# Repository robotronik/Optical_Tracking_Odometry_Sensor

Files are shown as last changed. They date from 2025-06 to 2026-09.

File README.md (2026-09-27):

Robotronik Optical Tracking Odometry Sensor
========================================

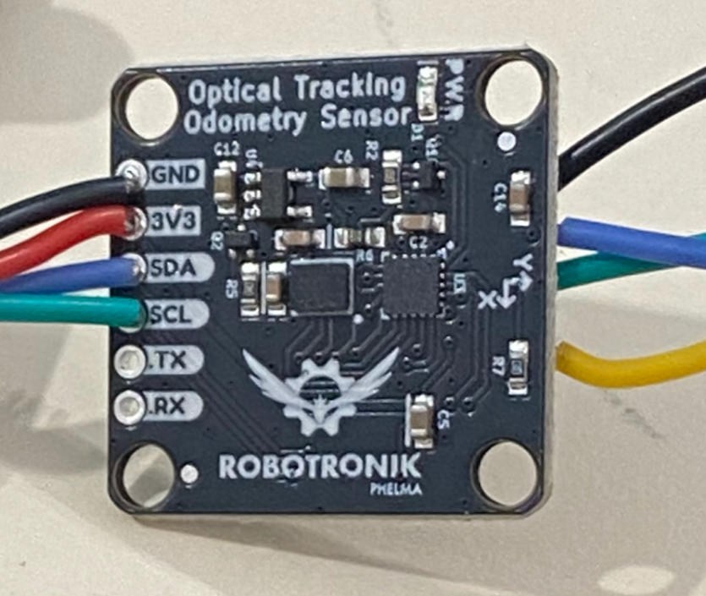
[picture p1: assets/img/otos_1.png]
Robotronik Optical Tracking Odometry Sensor [SEN-24904]


[*Robotronik Optical Tracking Odometry Sensor [SEN-24904]*](https://www.sparkfun.com/products/24904)

The Robotronik Optical Tracking Odometry Sensor empowers you to elevate your robot's navigation capabilities with exceptional precision and streamlined integration. This compact, all-in-one sensor leverages the power of the PAA5163E1 chip from PixArt Imaging Inc., delivering accurate dual-axis motion data across various hard floor surfaces. But that's not all! This sensor boasts a powerful built-in 6-axis Inertial Measurement Unit (IMU) and an onboard microcontroller that performs real-time sensor fusion and tracking algorithms.

Repository Contents
-------------------

* **/Hardware** - Kicad 9 Design
* **/Production** - Production panel files

Documentation
--------------
* **[Arduino Library](https://github.com/sparkfun/SparkFun_Qwiic_OTOS_Arduino_Library)** - Arduino library for the SparkFun Optical Tracking Odometry Sensor.
* **[Hookup Guide](https://docs.sparkfun.com/SparkFun_Optical_Tracking_Odometry_Sensor/)** - Hookup guide for the SparkFun Optical Tracking Odometry Sensor.

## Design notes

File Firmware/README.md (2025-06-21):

# SparkFun OTOS (Optical Tracking Odometry Sensor) Firmware

This folder contains the firmware used on the [SparkFun Optical Tracking Odometry Sensor](https://www.sparkfun.com/products/24904). Instructions are provided below for anyone wanting to change the firmware on their OTOS.

## Firmware Update

The recommended update procedure is to use the [STM32CubeProgrammer](https://www.st.com/en/development-tools/stm32cubeprog.html) to flash the provided .hex firmware file using the UART interface. The SWD test points on the OTOS can also be used with a debugger, but instructions are not provided here.

### Required Materials

* A [SparkFun Optical Tracking Odometry Sensor](https://www.sparkfun.com/products/24904) to be updated
* A USB to serial adapter, such as the [SparkFun Serial Basic Breakout](https://www.sparkfun.com/products/15096)
* [Jumper wires](https://www.sparkfun.com/products/12795) to connect the serial adapter to the OTOS
* Download the [STM32CubeProgrammer](https://www.st.com/en/development-tools/stm32cubeprog.html) and install it onto your computer
* Download the latest .hex file [from the releases tab](https://github.com/sparkfun/SparkFun_Optical_Tracking_Odometry_Sensor/releases) or [from the main branch](https://github.com/sparkfun/SparkFun_Optical_Tracking_Odometry_Sensor/tree/main/Firmware/Release)

### Procedure

1. The STM32 on the OTOS needs to be running its bootloader to flash the new firmware.
    * To do this, the BOOT0 pin must be held high when the STM32 boots up (during power up or a reset). This is broken out to the centermost test point on the bottom of the OTOS. It is suggested to touch a jumper wire connected to 3.3V to this test point while powering up the board - the STM32 will remain in the bootloader until it resets, loses power, or new code is flashed onto it.
2. Connect the serial converter TX and RX pins to IO10 and IO9 respectively.
3. Open the STM32CubeProgrammer. In the top right, select the UART interface, leave the UART configuration at the default settings, and click the Connect button.
    * If it fails to connect, ensure the right COM port is selected and is not used by anything else on your computer, ensure the OTOS is fully powered, ensure the bootloader is running (see Step 1), and ensure the TX and RX pins are correct.
4. Once connected, select the "Erasing & programming" tab on the left. In the "Download" section, select the .hex file to be flashed in the File path, then click "Start Programming"
5. Once complete, the OTOS should start running the new firmware immediately, and will disconnect from the STM32CubeProgrammer.

## Building the Firmware

The firmware was developed using the [STM32CubeIDE](https://www.st.com/en/development-tools/stm32cubeide.html), which you will need to install in order to build the firmware. It generates code for the low-level hardware functionality, so be aware that code within the `Core` directory may be modified by the code generator if not placed in the correct locations.

To import the project, open the STM32CubeIDE -> File -> Import... -> General -> Existing Projects into Workspace -> Next -> set root directory to this folder called Firmware -> Ensure SparkFun_OTOS_Firmware is selected -> Finish. You should now see the SparkFun_OTOS_Firmware project in the Project Explorer on the left. Once open, you should also change the build configuration from Debug to Release: Project -> Build Configurations -> Set Active -> 2 Release.

To build the project, within the STM32CubeIDE, -> Project -> Build Project. The output .hex file will be placed in the `Release` directory (assuming you've changed the build configuration from Debug to Release).

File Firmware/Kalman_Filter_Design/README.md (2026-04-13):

# SparkFun OTOS Kalman Filter Design

This folder contains the simulation that was used to design the Kalman filter for the [SparkFun Optical Tracking Odometry Sensor](https://www.sparkfun.com/products/24904). This script can be run in either [MATLAB](https://www.mathworks.com/products/matlab.html) (not tested) or [GNU Octave](https://octave.org/) (free). This is mainly provided for transparency on how the Kalman filter was designed and tuned, although you're welcome to play around with it and try to improve it!

The Kalman filter is what performs the sensor fusion between the acceleration measurements from the IMU (LSM6DSO), and the velocity measurements from the optical tracking sensor (PAA5163). The LSM6DSO acceleration measurements were measured to have a standard deviation of about 0.03 m/s^2, and the PAA5163 velocity measurements were measured to have a standard deviation of about 3 in/s (0.076 m/s).

The process noise covariance matrix Q was manually tuned to give a good balance of fast response times and low noise. The simulation also includes a handful of tests to verify robustness, such as loss of optical tracking data and acceleration offsets.

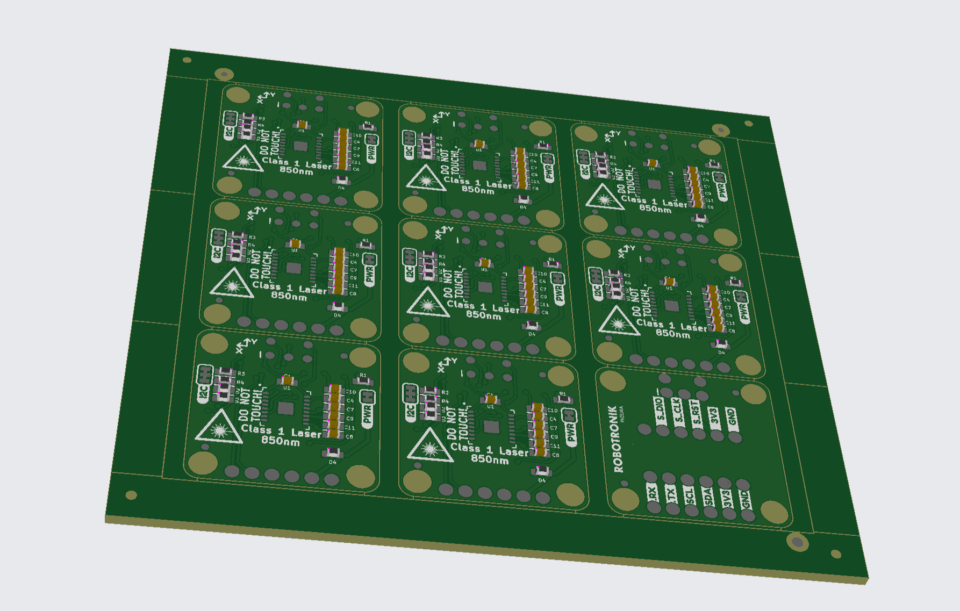
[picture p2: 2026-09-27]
assets/img/panel_jlc_1.png

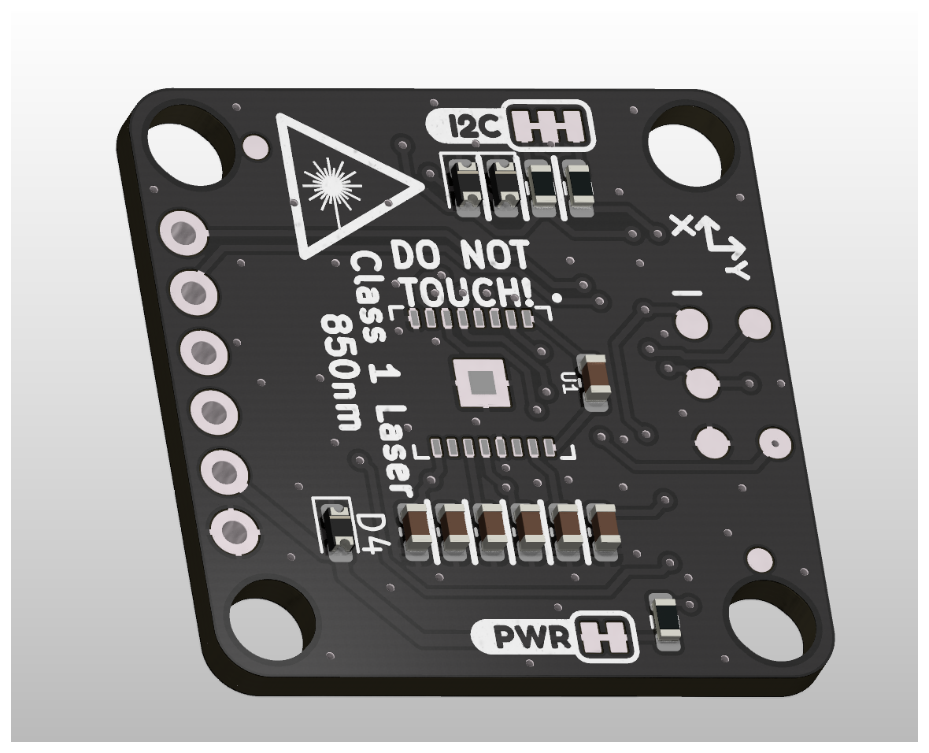
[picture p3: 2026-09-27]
assets/img/otos_cad_bot.png

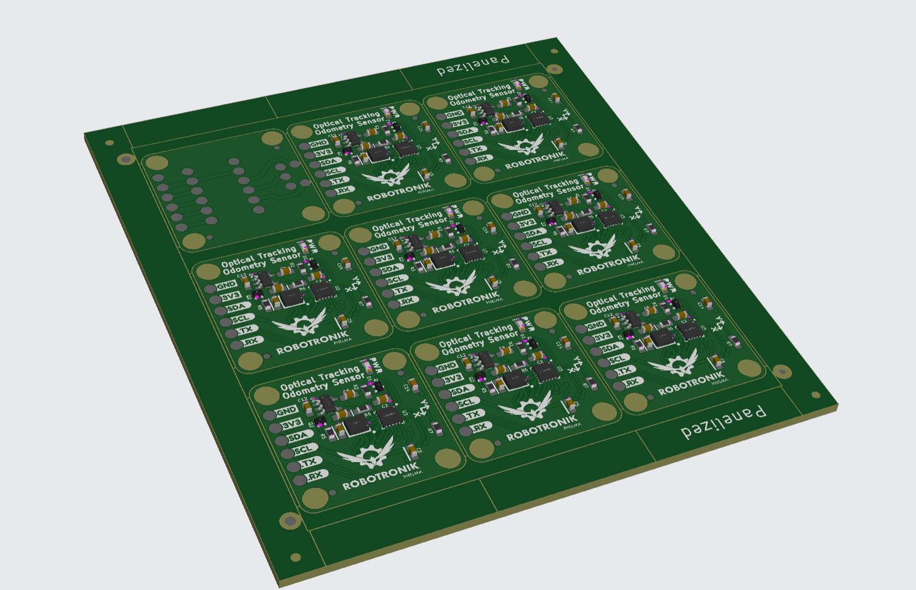
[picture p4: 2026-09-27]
assets/img/panel_jlc_2.png

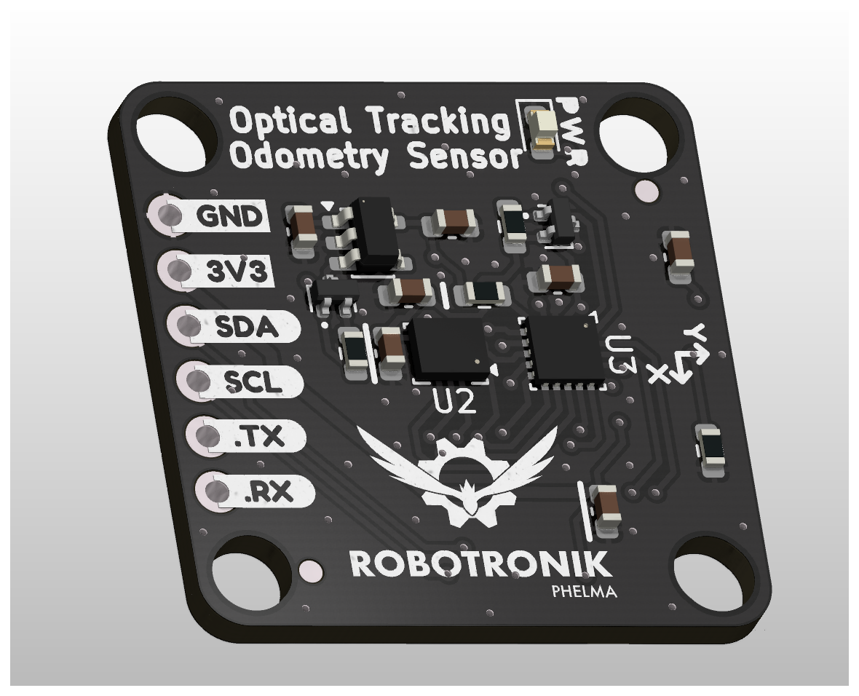
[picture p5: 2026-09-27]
assets/img/otos_cad_top.png

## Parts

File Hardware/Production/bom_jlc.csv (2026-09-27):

Designator | Footprint | Quantity | Value | LCSC Part #
C1_8, C1_7, C1_6, C1_5, C1_4, C1_3, C1_2, C1 | 603 | 8 | 470pF | C1620
C10_8, C10_7, C10_6, C10_5, C10_4, C10_3, C10_2, C10, C11_8, C11_7, C11_6, C11_5, C11_4, C11_3, C11_2, C11 | 603 | 16 | 4.7uF | C19666
C12_8, C12_7, C12_6, C12_5, C12_4, C12_3, C12_2, C12, C5_8, C5_7, C5_6, C5_5, C5_4, C5_3, C5_2, C5, C6_8, C6_7, C6_6, C6_5, C6_4, C6_3, C6_2, C6 | 603 | 24 | 22uF | C59461
C13_8, C13_7, C13_6, C13_5, C13_4, C13_3, C13_2, C13, C14_8, C14_7, C14_6, C14_5, C14_4, C14_3, C14_2, C14, C2_8, C2_7, C2_6, C2_5, C2_4, C2_3, C2_2, C2, C3_8, C3_7, C3_6, C3_5, C3_4, C3_3, C3_2, C3, C4_8, C4_7, C4_6, C4_5, C4_4, C4_3, C4_2, C4, C7_8, C7_7, C7_6, C7_5, C7_4, C7_3, C7_2, C7, C8_8, C8_7, C8_6, C8_5, C8_4, C8_3, C8_2, C8, C9_8, C9_7, C9_6, C9_5, C9_4, C9_3, C9_2, C9 | 603 | 64 | 0.1uF | C14663
D1_8, D1_7, D1_6, D1_5, D1_4, D1_3, D1_2, D1 | LED-0603 | 8 | Blue | C2286
D2_8, D2_7, D2_6, D2_5, D2_4, D2_3, D2_2, D2, D3_8, D3_7, D3_6, D3_5, D3_4, D3_3, D3_2, D3, D4_8, D4_7, D4_6, D4_5, D4_4, D4_3, D4_2, D4 | 603 | 24 | 24V | C2929252
Q1_8, Q1_7, Q1_6, Q1_5, Q1_4, Q1_3, Q1_2, Q1, Q2_8, Q2_7, Q2_6, Q2_5, Q2_4, Q2_3, Q2_2, Q2 | SOT-416FL | 16 | 100mA/20V/3.8Ω | C703629
R1_8, R1_7, R1_6, R1_5, R1_4, R1_3, R1_2, R1 | 603 | 8 | 4.7k | C23162
R2_8, R2_7, R2_6, R2_5, R2_4, R2_3, R2_2, R2, R5_8, R5_7, R5_6, R5_5, R5_4, R5_3, R5_2, R5, R7_8, R7_7, R7_6, R7_5, R7_4, R7_3, R7_2, R7 | 603 | 24 | 100k | C25803
R3_8, R3_7, R3_6, R3_5, R3_4, R3_3, R3_2, R3, R4_8, R4_7, R4_6, R4_5, R4_4, R4_3, R4_2, R4 | 603 | 16 | 2.2k | C4190
R6_8, R6_7, R6_6, R6_5, R6_4, R6_3, R6_2, R6 | 603 | 8 | 1k | C21190
U2_8, U2_7, U2_6, U2_5, U2_4, U2_3, U2_2, U2 | LGA14L | 8 | LSM6DS0 | C2829074
U3_8, U3_7, U3_6, U3_5, U3_4, U3_3, U3_2, U3 | STM32C011F6U6 | 8 | STM32C011F6U6 | C5456206
U4_8, U4_7, U4_6, U4_5, U4_4, U4_3, U4_2, U4 | SOT23-5 | 8 | RT9080-18GJ5 | C426476

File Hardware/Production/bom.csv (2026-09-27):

Designator | Footprint | Quantity | Value | LCSC Part #
_34, _33, _32, _31, _30, _29, _28, _27, _26, _25, _24, _23, _22, _21, _20, _19, _18, _17, _16, _15, _14, _13, _12, _11, _10, _9, _8 |  | 27
C1_8, C1_7, C1_6, C1_5, C1_4, C1_3, C1_2, C1 | 0603 | 8 | 470pF
C10_8, C10_7, C10_6, C10_5, C10_4, C10_3, C10_2, C10, C11_8, C11_7, C11_6, C11_5, C11_4, C11_3, C11_2, C11 | 0603 | 16 | 4.7uF
C12_8, C12_7, C12_6, C12_5, C12_4, C12_3, C12_2, C12, C5_8, C5_7, C5_6, C5_5, C5_4, C5_3, C5_2, C5, C6_8, C6_7, C6_6, C6_5, C6_4, C6_3, C6_2, C6 | 0603 | 24 | 22uF
C13_8, C13_7, C13_6, C13_5, C13_4, C13_3, C13_2, C13, C14_8, C14_7, C14_6, C14_5, C14_4, C14_3, C14_2, C14, C2_8, C2_7, C2_6, C2_5, C2_4, C2_3, C2_2, C2, C3_8, C3_7, C3_6, C3_5, C3_4, C3_3, C3_2, C3, C4_8, C4_7, C4_6, C4_5, C4_4, C4_3, C4_2, C4, C7_8, C7_7, C7_6, C7_5, C7_4, C7_3, C7_2, C7, C8_8, C8_7, C8_6, C8_5, C8_4, C8_3, C8_2, C8, C9_8, C9_7, C9_6, C9_5, C9_4, C9_3, C9_2, C9 | 0603 | 64 | 0.1uF
D1_8, D1_7, D1_6, D1_5, D1_4, D1_3, D1_2, D1 | LED-0603 | 8 | Blue
D2_8, D2_7, D2_6, D2_5, D2_4, D2_3, D2_2, D2, D3_8, D3_7, D3_6, D3_5, D3_4, D3_3, D3_2, D3, D4_8, D4_7, D4_6, D4_5, D4_4, D4_3, D4_2, D4 | 0603 | 24 | 24V
FD1_9, FD1_8, FD1_7, FD1_6, FD1_5, FD1_4, FD1_3, FD1_2, FD1, FD2_9, FD2_8, FD2_7, FD2_6, FD2_5, FD2_4, FD2_3, FD2_2, FD2, FD3_9, FD3_8, FD3_7, FD3_6, FD3_5, FD3_4, FD3_3, FD3_2, FD3, FD4_9, FD4_8, FD4_7, FD4_6, FD4_5, FD4_4, FD4_3, FD4_2, FD4 | FIDUCIAL-1X2 | 36 | FIDUCIAL1X2
FRAME1 | CREATIVE_COMMONS | 1 | FRAME-LETTER
H1_18, H1_17, H1_16, H1_15, H1_14, H1_13, H1_12, H1_11, H1_10, H1_9, H1_8, H1_7, H1_6, H1_5, H1_4, H1_3, H1_2, H1, H2_9, H2_8, H2_7, H2_6, H2_5, H2_4, H2_3, H2_2, H2, H3_9, H3_8, H3_7, H3_6, H3_5, H3_4, H3_3, H3_2, H3, H4_9, H4_8, H4_7, H4_6, H4_5, H4_4, H4_3, H4_2, H4 | STAND-OFF | 45 | STAND-OFF
I2C0_8, I2C0_7, I2C0_6, I2C0_5, I2C0_4, I2C0_3, I2C0_2, I2C0 | SMT-JUMPER_3_2-NC_TRACE_SILK | 8 | JUMPER-SMT_3_2-NC_TRACE_SILK
J3_11, J3_10, J3_9, J3_8, J3_7, J3_6, J3_5, J3_4, J3_3, J3_2, J3 | 1X06_NO_SILK | 11 | CONN_06NO_SILK_NO_POP
PWR0_8, PWR0_7, PWR0_6, PWR0_5, PWR0_4, PWR0_3, PWR0_2, PWR0 | SMT-JUMPER_2_NC_TRACE_SILK | 8 | JUMPER-SMT_2_NC_TRACE_SILK
Q1_8, Q1_7, Q1_6, Q1_5, Q1_4, Q1_3, Q1_2, Q1, Q2_8, Q2_7, Q2_6, Q2_5, Q2_4, Q2_3, Q2_2, Q2 | SOT-416FL | 16 | 100mA/20V/3.8Ω
R1_8, R1_7, R1_6, R1_5, R1_4, R1_3, R1_2, R1 | 0603 | 8 | 4.7k
R2_8, R2_7, R2_6, R2_5, R2_4, R2_3, R2_2, R2, R5_8, R5_7, R5_6, R5_5, R5_4, R5_3, R5_2, R5, R7_8, R7_7, R7_6, R7_5, R7_4, R7_3, R7_2, R7 | 0603 | 24 | 100k
R3_8, R3_7, R3_6, R3_5, R3_4, R3_3, R3_2, R3, R4_8, R4_7, R4_6, R4_5, R4_4, R4_3, R4_2, R4 | 0603 | 16 | 2.2k
R6_8, R6_7, R6_6, R6_5, R6_4, R6_3, R6_2, R6 | 0603 | 8 | 1k
U$1_9, U$1_8, U$1_7, U$1_6, U$1_5, U$1_4, U$1_3, U$1_2 | PAD_05_03X2_TP_NO4 | 8 | SWD-5PIN
U$1 | Pogo_Pins | 1 | SWD-5PIN
U$18_8, U$18_7, U$18_6, U$18_5, U$18_4, U$18_3, U$18_2, U$18, U$30_8, U$30_7, U$30_6, U$30_5, U$30_4, U$30_3, U$30_2, U$30 | X0 | 16
U$25_8, U$25_7, U$25_6, U$25_5, U$25_4, U$25_3, U$25_2, U$25 | PWR0 | 8
U$29_8, U$29_7, U$29_6, U$29_5, U$29_4, U$29_3, U$29_2, U$29, U$31_8, U$31_7, U$31_6, U$31_5, U$31_4, U$31_3, U$31_2, U$31 | Y0 | 16
U1_8, U1_7, U1_6, U1_5, U1_4, U1_3, U1_2, U1 | PAA5163E1-Q | 8 | PAA5163E1-Q
U2_8, U2_7, U2_6, U2_5, U2_4, U2_3, U2_2, U2 | LGA14L | 8 | LSM6DS0
U3_8, U3_7, U3_6, U3_5, U3_4, U3_3, U3_2, U3 | STM32C011F6U6 | 8 | STM32C011F6U6
U4_8, U4_7, U4_6, U4_5, U4_4, U4_3, U4_2, U4 | SOT23-5 | 8 | RT9080-18GJ5

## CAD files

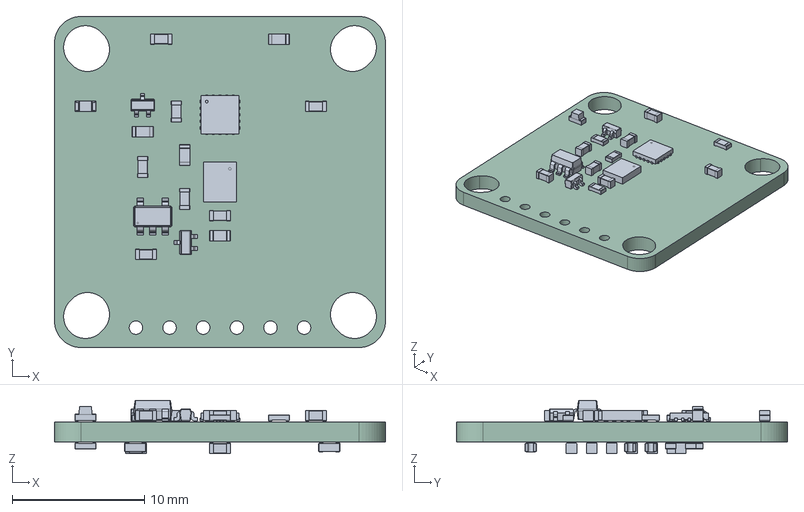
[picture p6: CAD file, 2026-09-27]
assets/models/Optical_Tracetry_Sensor.step
25.0 x 25.0 x 4.03 mm
R_0603_1608Metric x 7
C_0603_1608Metric x 14
LGA-14_3x2.5mm_P0.5mm_LayoutBorder3x4y
sot416 x 2
ST_UFQFPN-20_3x3mm_P0.5mm
LED_0603_1608Metric
SOT-23-5
D_0603_1608Metric x 3
Optical_Tracking_Odometry_Sensor_PCB

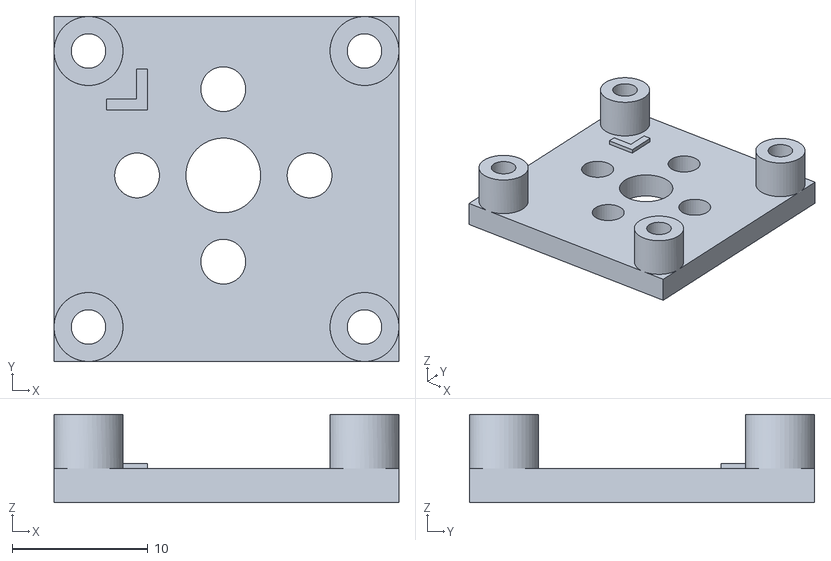
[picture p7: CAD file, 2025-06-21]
Firmware/Lookup_Table_Calibration/3D_Printables/stepper_otos_mount.stl
25.4 x 25.4 x 6.50

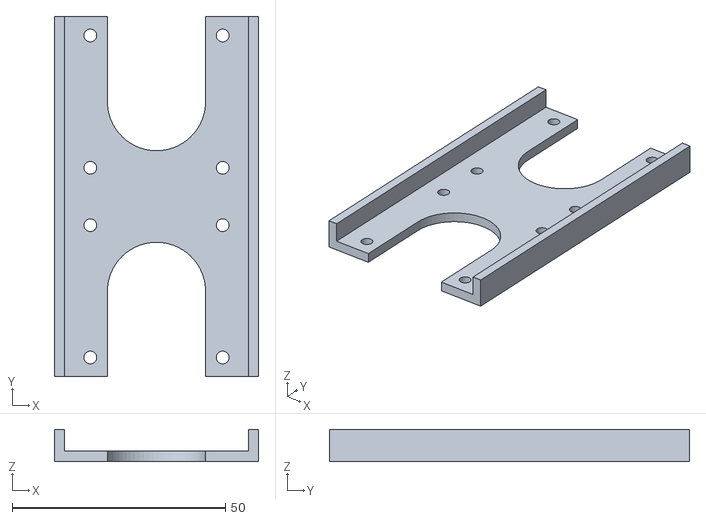
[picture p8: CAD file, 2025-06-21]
Firmware/Lookup_Table_Calibration/3D_Printables/stepper_motor_bracket.stl
47.8 x 84.4 x 7.50

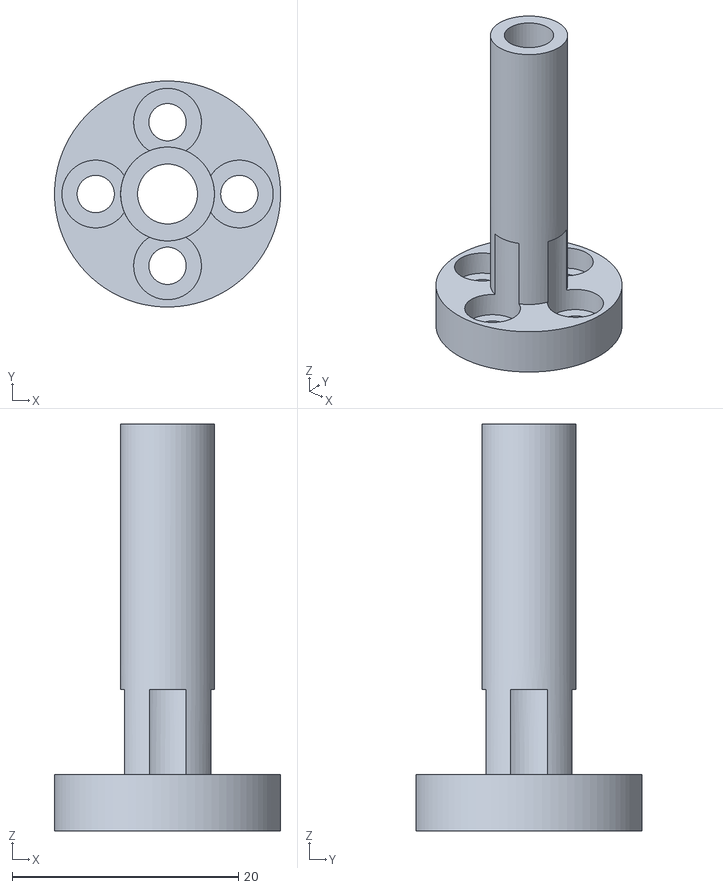
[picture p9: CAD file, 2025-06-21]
Firmware/Lookup_Table_Calibration/3D_Printables/stepper_disc_mount.stl
20.0 x 20.0 x 36.0

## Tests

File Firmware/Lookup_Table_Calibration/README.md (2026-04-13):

# SparkFun OTOS Lookup Table Calibration

This folder contains the scripts and files that were used to create the lookup table calibration for the [SparkFun Optical Tracking Odometry Sensor](https://www.sparkfun.com/products/24904). This is mainly provided for transparency on how the lookup table was created. **This is not a tutorial, and no support will be provided for anyone attempting to do this themselves!** This requires many pieces of software and hardware, some details are ommitted, and it can take **many hours** to go from nothing to a final lookup table.

## Precursory Info

The PAA5163 is the optical tracking sensor used on the board, and it was discovered in testing that there is resolution variation based on how fast the surface is moving. However the resolution variation is nonlinear, and the variation for one axis depends on the velocity in both axes. Below is a plot of the x-axis resolution variation (measured velocity divided by true velocity) versus the true velocity in both axes, where the color scale goes from 0.9 (purple) to 1.0 (yellow):

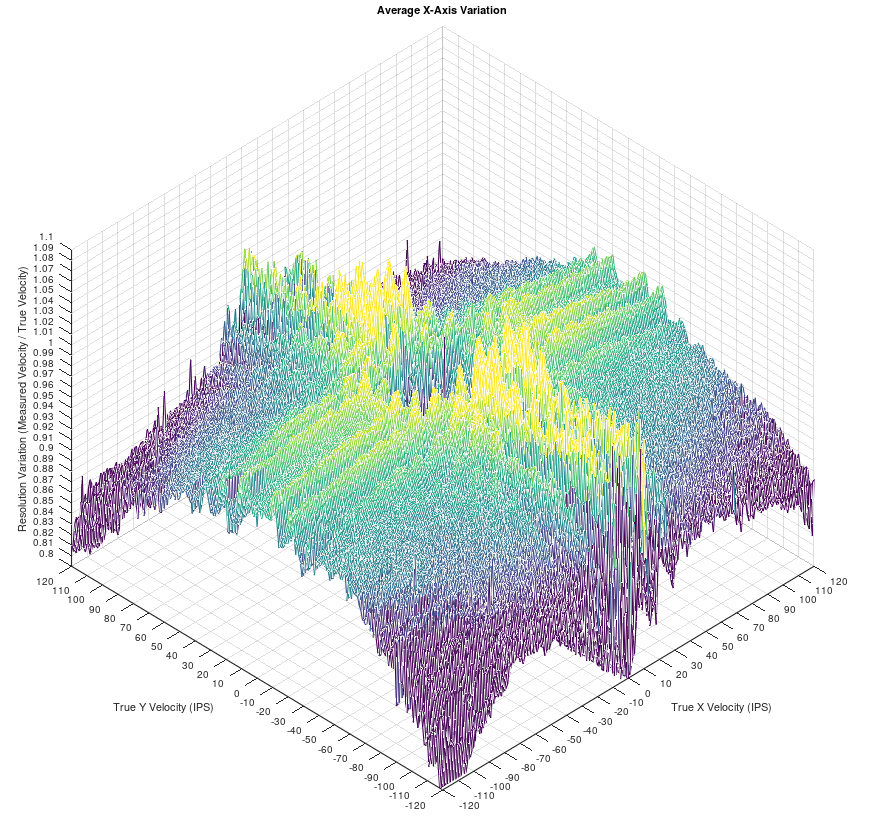
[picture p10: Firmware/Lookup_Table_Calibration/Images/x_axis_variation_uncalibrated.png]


Ideally, this should be a flat surface, but has the overall shape of an inverted paraboloid with ridges in both directions. The y-axis is similar, but with flipped x and y axes. The y-axis is also slightly asymetric, likely due to the laser being off-center from the sensor.

Testing has shown this variation to be consitent per sensor, and fairly similar between different sensors. The idea to correct this is to store this variation in the firmware, then at every time step, measure the velocity and multiply it by the inverse of the variation at that velocity. Theoretically, this should cause the surface to become flat.

Rather than storing the variation, the inverse (referred to as the scalar lookup table) is stored in order to reduce the amount of floating point division in each loop iteration to optimize performance. The image below is shows the scalar lookup table versus the *measured* velocity in both axes (instead of the *true* velocity, since that's not known at runtime):

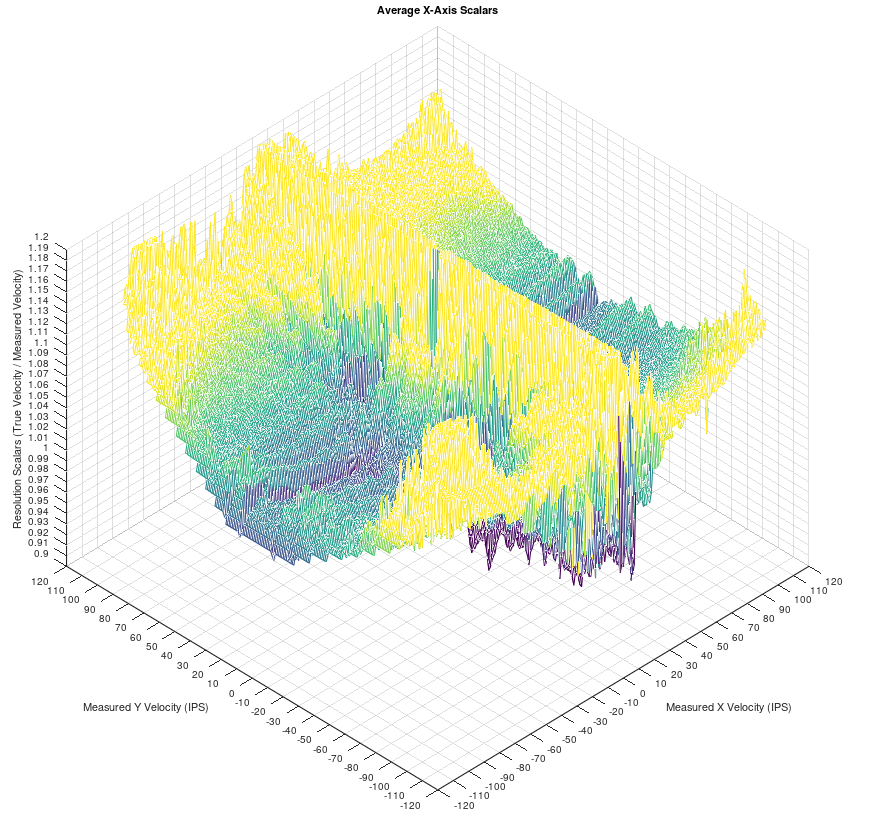
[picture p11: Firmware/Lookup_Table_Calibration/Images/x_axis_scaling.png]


The firmware needs to store this lookup table up to +/- 100 in/s (2.5m/s), which is the max rated speed of the PAA5163. The lookup table in the image above has a resolution of 1 in/s, meaning 201 * 201 = 40,401 data points would need to be stored. The STM32C0 microcontroller on the board only has 32k of flash memory, so this needs to be stored more efficiently.

The main space savings here is to store a sparse version of this lookup tableT Firmware version v1.0 uses 51 * 51 = 2,601 data points; the 51 grid coordinate were chosen by hand to capture just the peaks and valleys. At every time step, the measured velocity is used to index into the lookup table, and a bilinear interpolation is used to approximate the correct scaling value. Below is an image of the sparse lookup table:

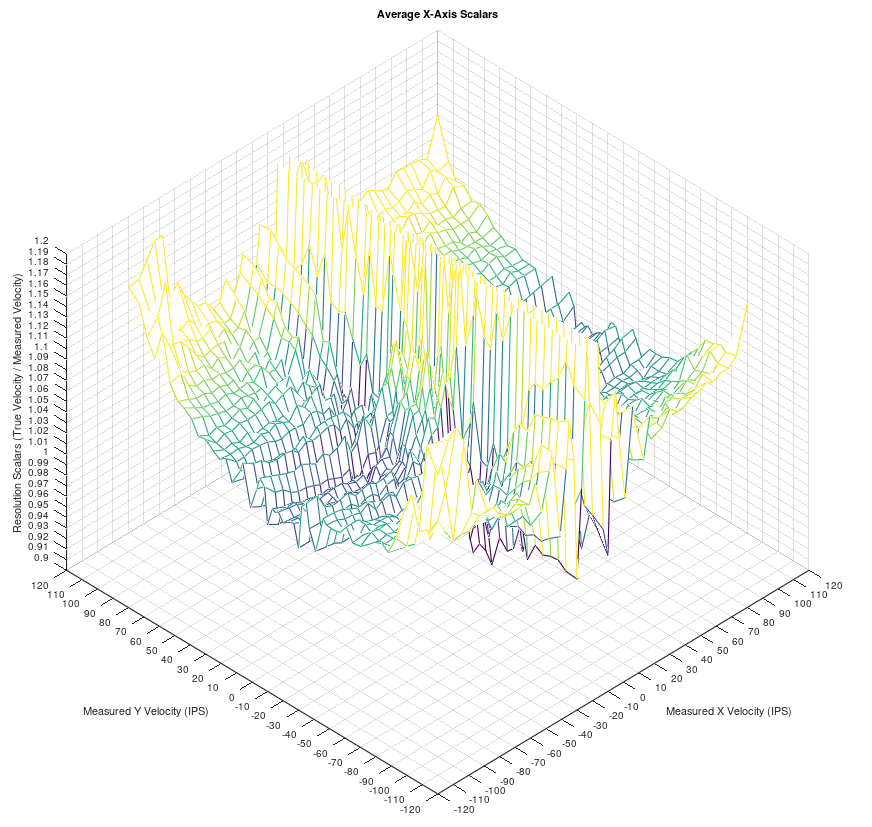
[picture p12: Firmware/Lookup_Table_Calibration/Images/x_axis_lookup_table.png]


The other memory saving measure is to store each value in a single byte, requiring only about 2.6kB (5.2kB total, since a separate lookup table is needed for each axis). Each byte has a resolution of 0.2%, allowing scaling values from 0.774 to 1.254.

To verify this makes an improvement, the resolution variation from the data in the first figure above is multiplied by the interpolated sparse lookup table, which results in the surface below, where the color scale goes from 0.98 (purple) to 1.02 (yellow):

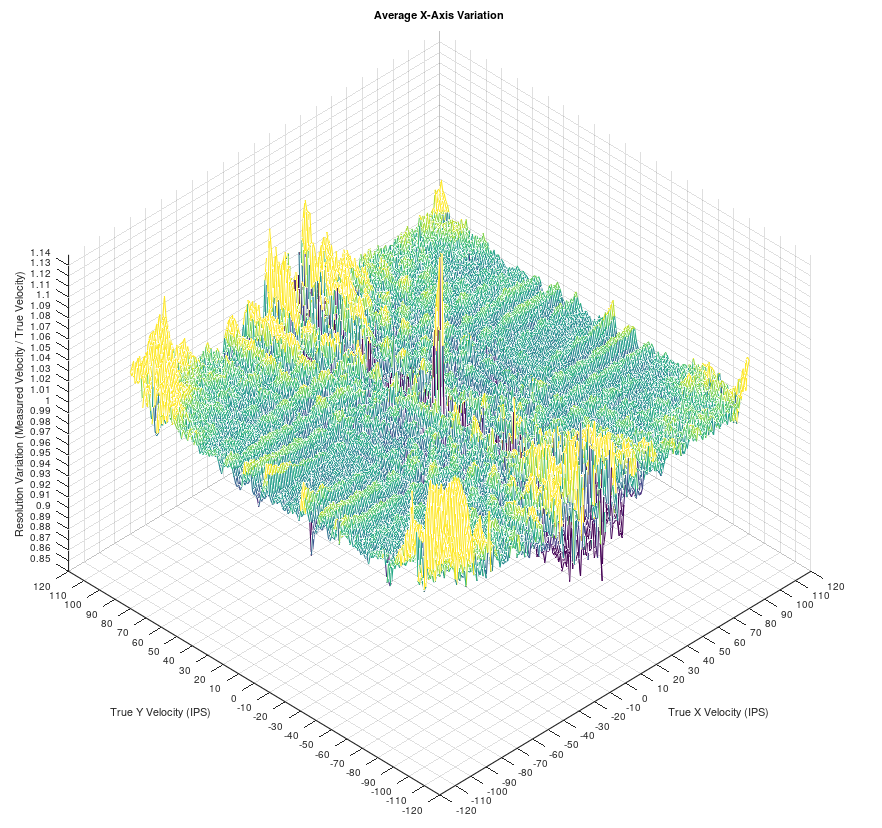
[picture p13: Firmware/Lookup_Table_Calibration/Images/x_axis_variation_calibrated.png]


The surface is overall much more flat than before. Some ridges are and other fluctuations are still present, at least partially due to the innaccuracy of the sparse lookup table. Although in reality there is more variation than this, since the measurement noise causes the lookup table to be indexed into the wrong place, meaning a slightly incorrect scaling value is used. But the main benefit is that the surface is overall flat instead of an inverted paraboloid.

## Materials Used

This calibration is done by spinning a disc of the surface in front of the sensor at a range of speeds and angles to generate the resolution variation data in the first image above. Below is an image of the setup used:

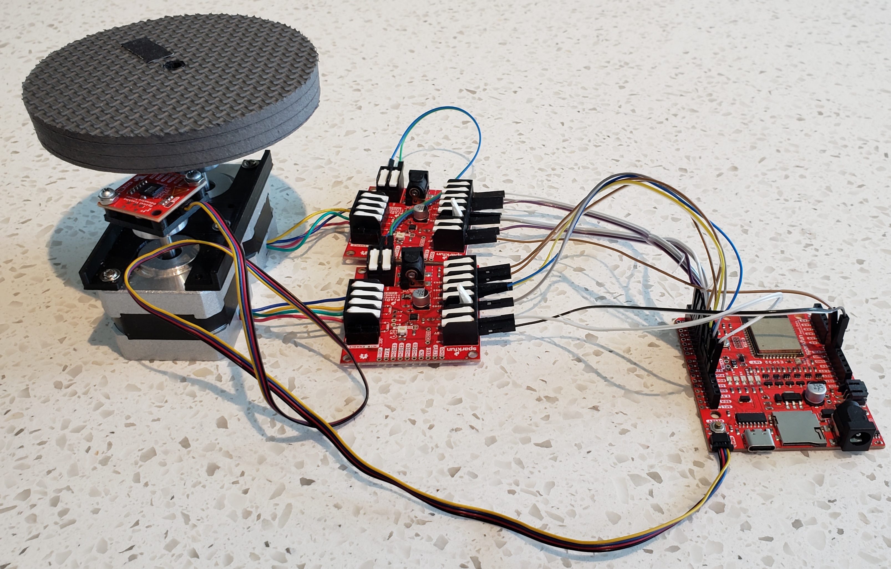
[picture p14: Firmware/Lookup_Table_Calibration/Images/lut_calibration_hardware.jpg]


This setup uses the following hardware:

* 1x [12V power supply](https://www.sparkfun.com/products/15313) (at least 500mA)
* 2x [stepper motors](https://www.sparkfun.com/products/9238)
* 2x [stepper motor hubs](https://www.sparkfun.com/products/10006)
* M3 and 4-40 screws
* 2x [stepper motor drivers](https://www.sparkfun.com/products/16836)
* 1x [ESP32 IoT RedBoard](https://www.sparkfun.com/products/19177)
* 1x [Optical Tracking Odometry Sensor](https://www.sparkfun.com/products/24904)
* [Jumper wires](https://www.sparkfun.com/products/12795)
* 1x [Qwiic Cable](https://www.sparkfun.com/products/17257)
* Disc of surface, at least 4" diameter
    * In this setup, an FTC foam tile was cut using a CNC milling machine into a 4" diameter disc with an 0.3" hole in the center for mounting
* 3D printed parts:
    * [Motor bracket](3D_Printables/stepper_motor_bracket.stl) (positions shafts 1.75" apart from each other)
    * [OTOS mount](3D_Printables/stepper_otos_mount.stl)
    * [Disc mount](3D_Printables/stepper_disc_mount.stl) (works with FTC foam tile disc, but another design may be needed for other discs)

And the following software is required:

* [Arduino IDE](https://www.arduino.cc/en/software) with [ESP32 core](https://github.com/espressif/arduino-esp32) to program the IoT RedBoard
* [MATLAB](https://www.mathworks.com/products/matlab.html) (not tested) or [GNU Octave](https://octave.org/) (free) to run included scripts
    * If using Octave,the [Intrument Control Package](https://octave.sourceforge.io/instrument-control/index.html) needs to be installed; a tutorial is available [here](https://www.edn.com/read-serial-data-directly-into-octave/)
* [STM32CubeIDE](https://www.st.com/en/development-tools/stm32cubeide.html) and [STM32CubeProgrammer](https://www.st.com/en/development-tools/stm32cubeprog.html) to modify, build, and flash the firmware with the new calibration to the sensor, see instructions [here](../README.md)

Again, this is not a tutorial, this is only documentation on how this lookup table calibration was done for transparency. If you want to do this yourself, you may need to substitute some items, design your own 3D printed mounts, modify some code, etc. **Support will not be provided, you'll be on your own!**

## Calibration Process

Note - This setup has the optical sensor oriented upwards. It includes an IR bandpass filter, so it is usually not necessary to block ambient light. However if the room has sunlight coming through a window, it may be necessary to add some kind of light shield around the setup, otherwise the optical sensor can lose tracking. This can be done with something like a large carboard box over the entire setup.

### Assembly

Assemble the setup as shown in the image above. Ensure the disc is positioned at a suitable distance from the sensor (10mm is used for the FTC foam tile). See the [Arduino sketch](Data_Collection/Data_Collection.ino) for the connections between the IoT RedBoard and stepper motor drivers. The stepper motor wires were connected to the drivers with the following pinout:

* A+ -> Blue
* A- -> Yellow
* B+ -> Red
* B- -> Green

The provided mount for the OTOS is not symmetric. The optical sensor on the board has the laser and sensing element slightly off-center, and this needs to be accounted for to get accurate data. The mount includes a feature indicating the intended orientation of the sensor, align the axes in the silkscreen with this feature.

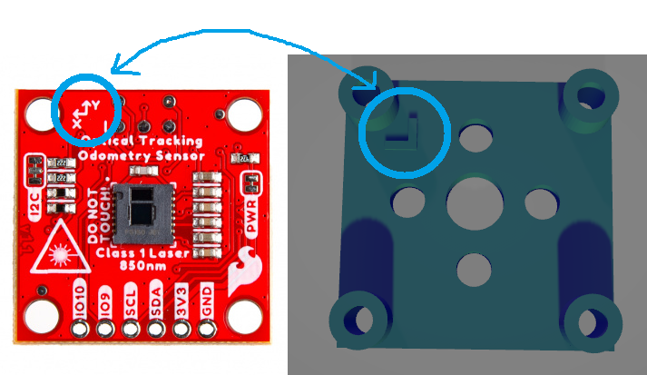
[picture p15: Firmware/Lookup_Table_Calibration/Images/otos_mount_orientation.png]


### Verification Test

The following tests should be performed to verify the setup is working. Open the [Arduino sketch](Data_Collection/Data_Collection.ino), then change the value of `currentTest` near the top of the sketch and run the following tests in order:

* OTOS Angle
    * This should rotate the OTOS stepper by +90 degrees, then -90 degrees. This will verify the correct motor is being controlled, and that it rotates in the correct direcion and angle.
* Disc Ramp
    * This should spin the disc stepper, ramping up to speed the max speed required by the final data collection test, then ramping back down to zero.
    * This test can also be used to ensure the disc does not wobble while spinning; it may be necessary to shim the 3D printed mount.
    * If the disc motor stops spinning at high speed, it may be necessary to add more mass so it has more inertia.
* Zero Angle
    * This should spin the disc stepper at a medium speed, then use the data from the optical sensor to zero the angle of the OTOS relative to the surface motion.

### OTOS Mount Centering

The mount will get the optical sensor close to centered on the motor shaft, but the mounting holes allow for some variation in exact location. The sensor should be positioned as close to center as possible to get the most accurate data for the final data collection test. This can be done using the mount centering test:

Edit the value of `currentTest` to run the mount centering test. This will first find the zero angle for the optical sensor, then sweep the disc through a range of speeds in all 4 orthogonal directions.

While the test is running, it is also necessary to run the [mounting test script](Data_Collection/otos_mounting_test.m) in MATLAB or Octave to collect the data from the test and generate the output plots. Set the COM port used by the IoT RedBoard near the top of the script, then run the script while the zero angle is being found to synchronize with the start of the test.

Once the test completes, 2x plots similar to the following should be displayed:

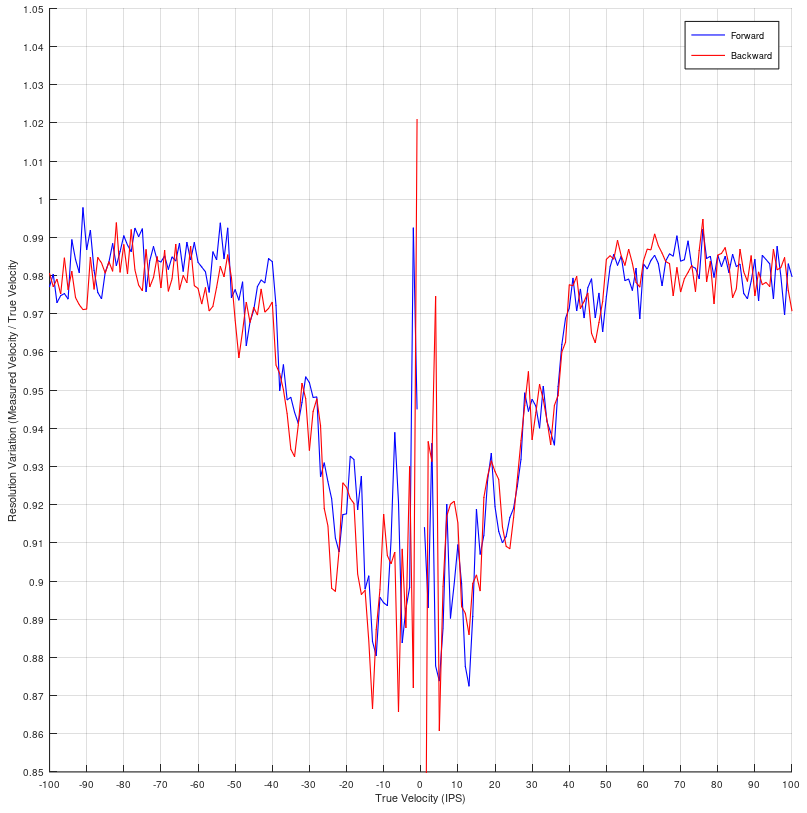
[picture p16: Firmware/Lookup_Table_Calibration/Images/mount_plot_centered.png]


If the red and blue lines overlap with each other in both plots like above, then the sensor is well centered. If it's not centered, there will be an offset between the lines like below:

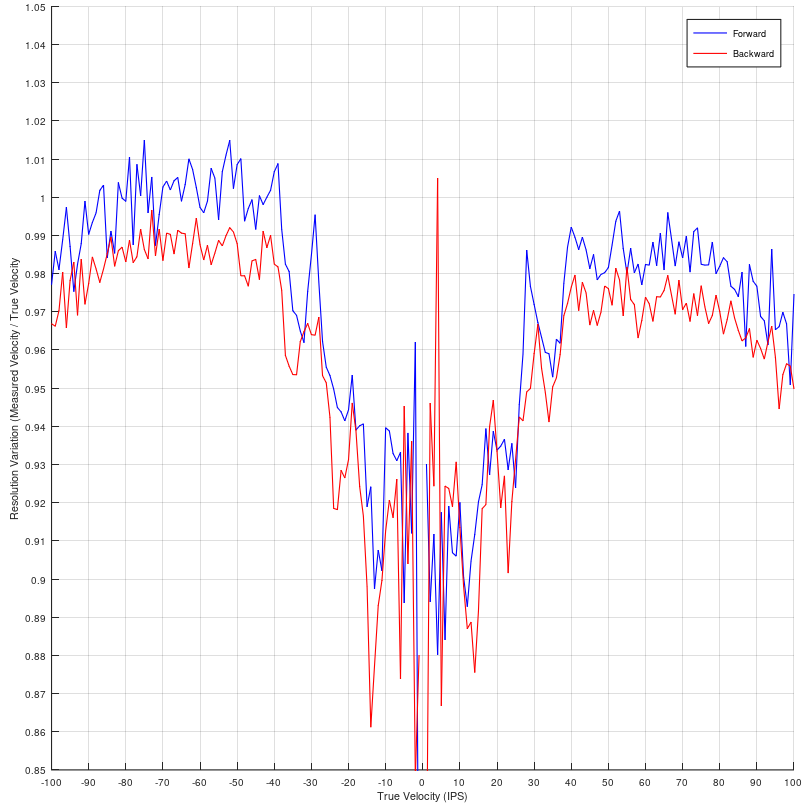
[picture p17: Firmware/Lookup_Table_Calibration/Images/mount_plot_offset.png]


In this case, the sensor needs to be re-mounted, and shifted in whatever direction causes the lines to overlap. The noise in the data can be reduced by increasing the value of `numSamples` near the top of the Arduino sketch, although this increases the amount of time the test takes.

### Data Collection

Once everything above has been completed, data collection can begin to create the lookup table. Edit the value of `currentTest` to run the data collection test. This will first find the zero angle for the optical sensor, then sweep the disc speed and sensor angle through a grid of velocities.

While the test is running, it is also necessary to run the [lookup table data collection script](Data_Collection/otos_mounting_test.m) in MATLAB or Octave to collect the data from the test and generate the output plots. Set the COM port used by the IoT RedBoard near the top of the script, then run the script while the zero angle is being found to synchronize with the start of the test.

Note - **THIS TEST TAKES A LONG TIME!** By default, it measures velocities from -120 to +120 in/sec with 1 in/sec resolution, which results in 241 * 241 = **58,081 data points**. With `numSamples` set to the default of 8, it makes about 16x measurements per second, so **this takes about an hour**. However if only a single sensor is calibrated, the data will likely be too noisy for a good lookup table, so it is recommended to increase `numSamples` by 8x (which increases the test time by the same amount). The lookup table used in firmware v1.0 was generated with `numSamples` set to 8, and averaged across 8 different sensors (effectively 64 samples per data point).

Note - In the final data collection test, the zero angle may be slightly off; this can be corrected by editing `correctionAngle` near the top of the sketch. This is easiest to identify early in the test if the output plot looks significantly asymmetric.

Once the test completes, the data will be saved to a pair of CSV files, which can be used in [this script](Calibration_Data/average_variation_and_compute_lookup_tables.m) to compute the final lookup tables. The CSV files included in [Calibration_Data](Calibration_Data/) folder is the data used to create the final lookup table used in firmware version v1.0.

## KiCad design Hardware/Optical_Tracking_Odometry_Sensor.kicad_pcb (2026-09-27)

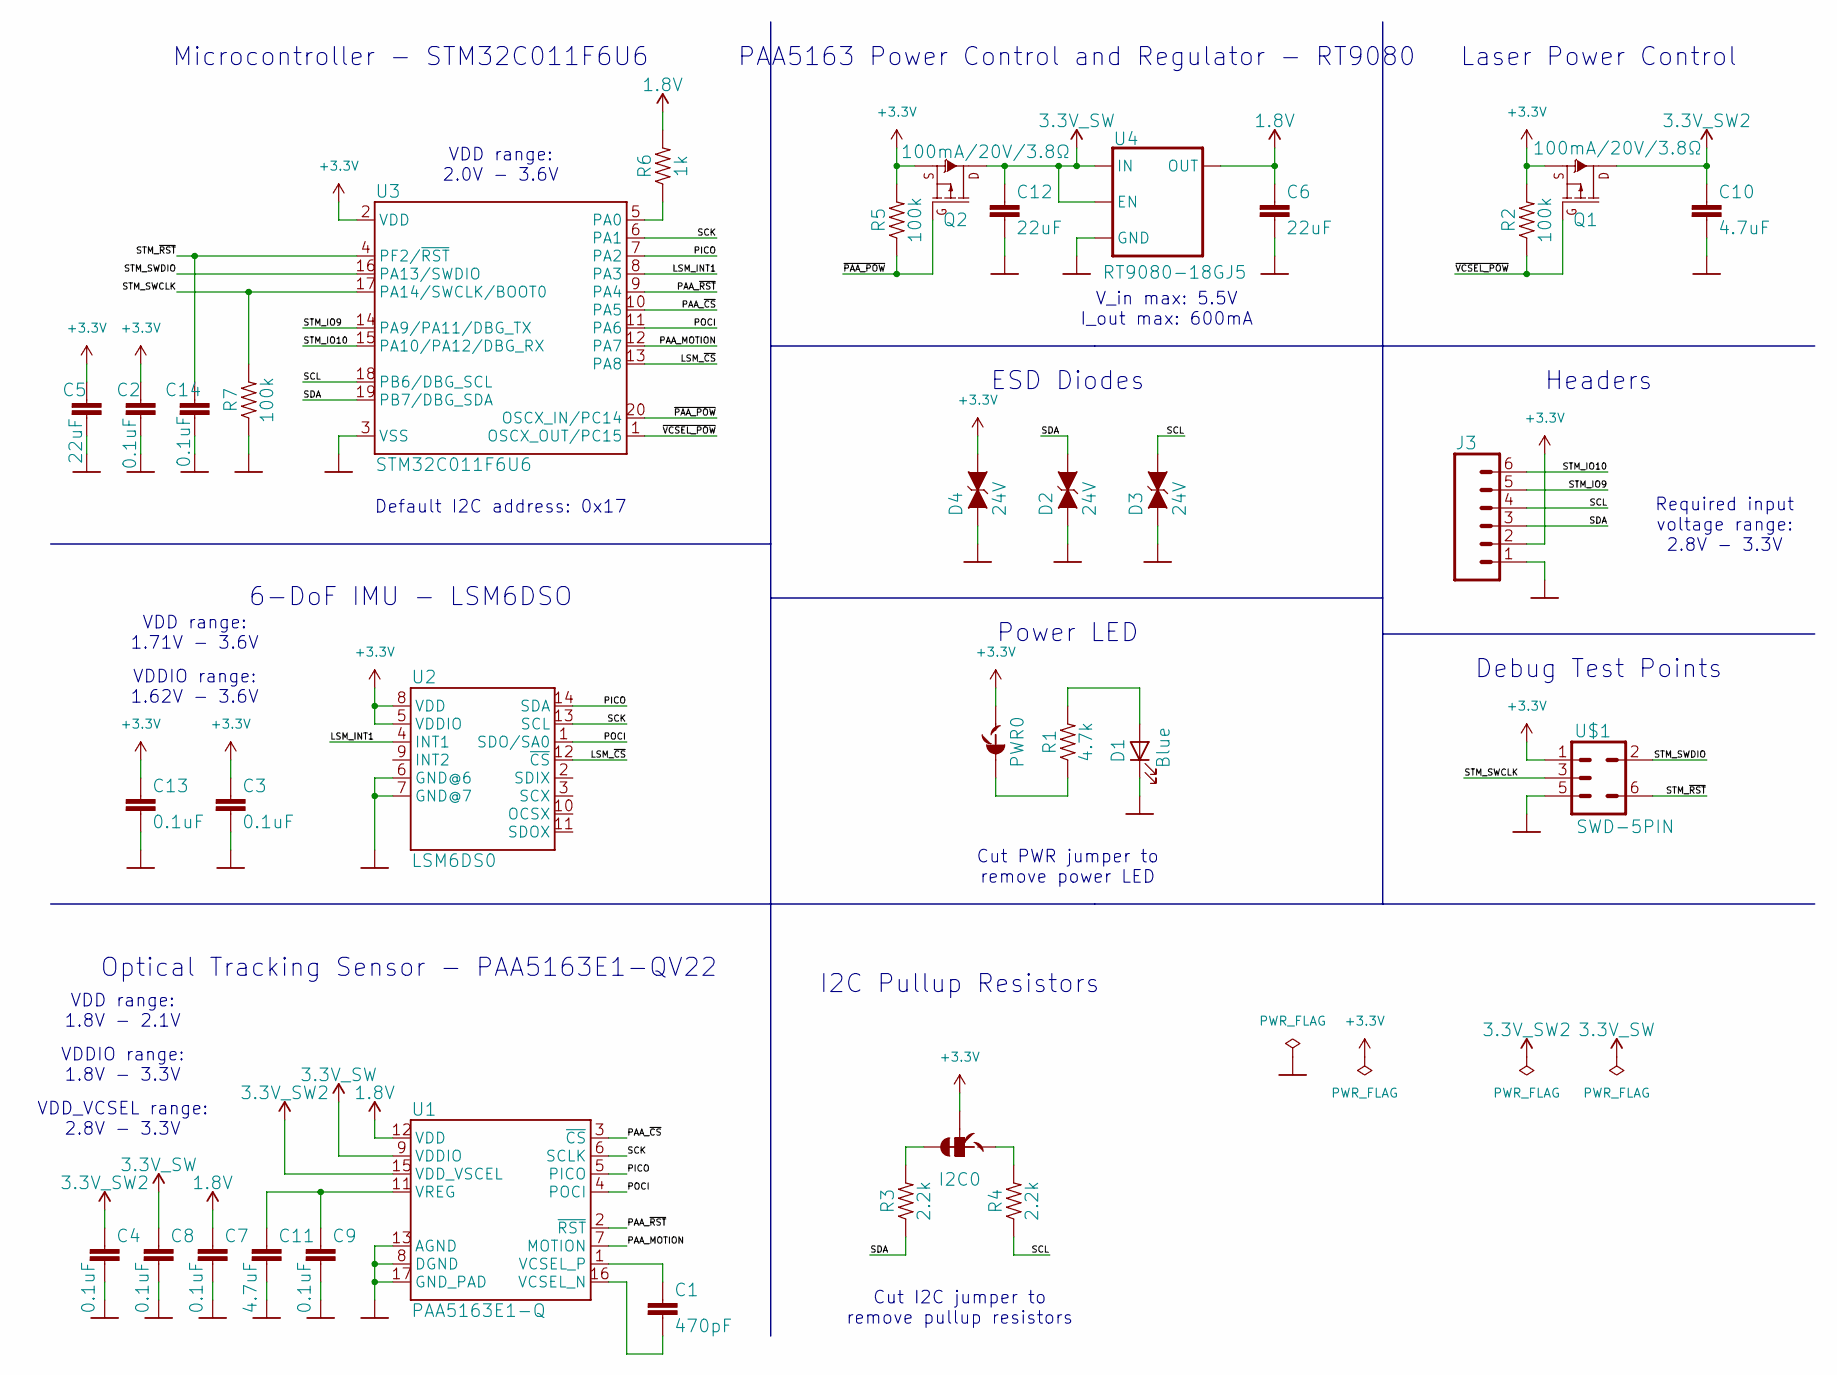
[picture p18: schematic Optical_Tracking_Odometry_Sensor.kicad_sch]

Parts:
C1: 470pF; C_0603_1608Metric
C2, C3, C4, C7, C8, C9, C13, C14: 0.1uF; C_0603_1608Metric
C5, C6, C12: 22uF; C_0603_1608Metric
C10, C11: 4.7uF; C_0603_1608Metric
D1: Blue; LED_0603_1608Metric
D2, D3, D4: 24V; D_0603_1608Metric
I2C0: JUMPER-SMT_3_2-NC_TRACE_SILK; SMT-JUMPER_3_2-NC_TRACE_SILK
J3: CONN_06NO_SILK_NO_POP; 1X06_NO_SILK
PWR0: JUMPER-SMT_2_NC_TRACE_SILK; SMT-JUMPER_2_NC_TRACE_SILK
Q1, Q2: 100mA/20V/3.8Ω; SOT-416
R1: 4.7k; R_0603_1608Metric
R2, R5, R7: 100k; R_0603_1608Metric
R3, R4: 2.2k; R_0603_1608Metric
R6: 1k; R_0603_1608Metric
U1: PAA5163E1-Q
U2: LSM6DS0; LGA-14_3x2.5mm_P0.5mm_LayoutBorder3x4y
U3: STM32C011F6U6; ST_UFQFPN-20_3x3mm_P0.5mm
U4: RT9080-18GJ5; SOT-23-5
U$1: SWD-5PIN; PAD_05_03X2_TP_NO4

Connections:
1.8V: C6.1, C7.1, R6.2, U1.12 (VDD), U4.5 (OUT)
3.3V_SW: C8.1, C12.1, Q2.3 (D), U1.9 (VDDIO), U4.1 (IN), U4.3 (EN)
3.3V_SW2: C4.1, C10.1, Q1.3 (D), U1.15 (VDD_VSCEL)
+3.3V: C2.1, C3.1, C5.1, C13.1, D4.2 (C), I2C0.2, J3.2, PWR0.2, Q1.2 (S), Q2.2 (S), R2.2, R5.2, U2.5 (VDDIO), U2.8 (VDD), U3.2 (VDD), U$1.1
/LSM_INT1: U2.4 (INT1), U3.8 (PA3)
/LSM_~CS: U2.12 (~CS), U3.13 (PA8)
/PAA_MOTION: U1.7 (MOTION), U3.12 (PA7)
/PAA_~CS: U1.3 (~CS), U3.10 (PA5)
/PAA_~RST: U1.2 (~RST), U3.9 (PA4)
/PICO: U1.5 (PICO), U2.14 (SDA), U3.7 (PA2)
/POCI: U1.4 (POCI), U2.1 (SDO/SA0), U3.11 (PA6)
/SCK: U1.6 (SCLK), U2.13 (SCL), U3.6 (PA1)
/SCL: D3.2 (C), J3.4, R4.1, U3.18 (PB6/DBG_SCL)
/SDA: D2.2 (C), J3.3, R3.1, U3.19 (PB7/DBG_SDA)
/STM_IO9: J3.5, U3.14 (PA9/PA11/DBG_TX)
/STM_IO10: J3.6, U3.15 (PA10/PA12/DBG_RX)
/STM_SWCLK: R7.2, U3.17 (PA14/SWCLK/BOOT0), U$1.3
/STM_SWDIO: U3.16 (PA13/SWDIO), U$1.2
/STM_~RST: C14.1, U3.4 (PF2/~RST), U$1.6
/~PAA_POW: Q2.1 (G), R5.1, U3.20 (OSCX_IN/PC14)
/~VCSEL_POW: Q1.1 (G), R2.1, U3.1 (OSCX_OUT/PC15)
GND: C2.2, C3.2, C4.2, C5.2, C6.2, C7.2, C8.2, C9.2, C10.2, C11.2, C12.2, C13.2, C14.2, D1.1 (K), D2.1 (A), D3.1 (A), D4.1 (A), J3.1, R7.1, U1.8 (DGND), U1.13 (AGND), U1.17 (GND_PAD), U2.6 (GND@6), U2.7 (GND@7), U3.3 (VSS), U4.2 (GND), U$1.5
unnamed: D1.2 (A), R1.2
unnamed: I2C0.1, R4.2
unnamed: I2C0.3, R3.2
unnamed: PWR0.1, R1.1
unnamed: C1.2, U1.16 (VCSEL_N)
unnamed: C1.1, U1.1 (VCSEL_P)
unnamed: C9.1, C11.1, U1.11 (VREG)
unnamed: R6.1, U3.5 (PA0)

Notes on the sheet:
Power LED
VDD range: 2.0V - 3.6V
I2C Pullup Resistors
6-DoF IMU - LSM6DSO
Microcontroller - STM32C011F6U6
Cut I2C jumper to remove pullup resistors
VDDIO range: 1.62V - 3.6V
VDDIO range: 1.8V - 3.3V
Debug Test Points
Cut PWR jumper to remove power LED
PAA5163 Power Control and Regulator - RT9080
Default I2C address: 0x17
VDD range: 1.8V - 2.1V
Required input voltage range: 2.8V - 3.3V
ESD Diodes
V_in max: 5.5V I_out max: 600mA
Headers
VDD_VCSEL range: 2.8V - 3.3V
Laser Power Control
Optical Tracking Sensor - PAA5163E1-QV22
VDD range: 1.71V - 3.6V

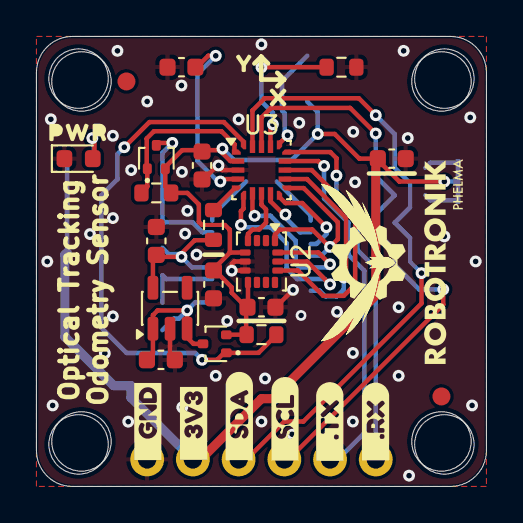
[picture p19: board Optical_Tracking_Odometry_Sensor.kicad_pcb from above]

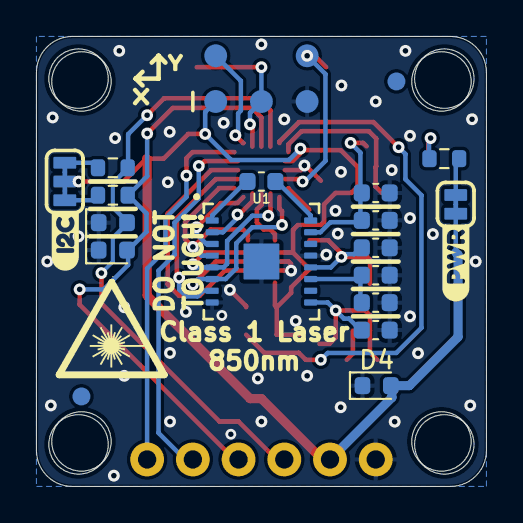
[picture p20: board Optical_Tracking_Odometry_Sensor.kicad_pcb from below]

Board: 2 copper layers, 25.0 x 25.0 mm, 58 parts (23 on the bottom side), 30 nets.

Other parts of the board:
FD1, FD2, FD3, FD4: FIDUCIAL1X2; FIDUCIAL-1X2
FRAME1: FRAME-LETTER; CREATIVE_COMMONS
H1, H1#2, H2, H3, H4: STAND-OFF
U$18, U$30: X0
U$25: PWR0
U$29, U$31: Y0
kibuzzard-68FE4A6E: G***; kibuzzard-68FE4A6E
kibuzzard-68FE4A91: G***; kibuzzard-68FE4A91
kibuzzard-68FE4AB9: G***; kibuzzard-68FE4AB9
kibuzzard-68FE4AC0: G***; kibuzzard-68FE4AC0
kibuzzard-68FE4B1F: G***; kibuzzard-68FE4B1F
kibuzzard-68FE4B2A: G***; kibuzzard-68FE4B2A
kibuzzard-68FE49AD: G***; kibuzzard-68FE49AD
kibuzzard-68FE4977: G***; kibuzzard-68FE4977

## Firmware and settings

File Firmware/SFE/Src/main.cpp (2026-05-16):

/*
    SPDX-License-Identifier: MIT
    
    Copyright (c) 2024 SparkFun Electronics
*/

#include "main.h"
#include "otosLsm6dso.h"
#include "otosPaa5163.h"
#include "registers.h"
#include "otosConstants.h"
#include "time.h"
#include "pose2d.h"
#include "adc.h"
#include "otosLut.h"
#include "otosKalmanFilter.h"
#include "arm_math.h"

// Helper function to calibrate the IMU. Must be stationary during calibration!
void calibrateImu(uint8_t numSamples);

// Helper function to get the latest sensor data and update the pose
void sensorUpdate();

// Helper function to update the main register copy from the self shadow
void copyRegsFromSelfShadow();

// Helper function to update the main register copy from the host shadow
void copyRegsFromHostShadow();

// Instances of the sensors
PAA5163 paa;
LSM6DSO lsm;

// Offset between OTOS and host, and its inverse
pose2d posHost;
pose2d posOffset;
pose2d posOffsetInv;

// IMU offset values
float accOffsetX = 0;
float accOffsetY = 0;
float gyrOffsetX = 0;
float gyrOffsetY = 0;
float gyrOffsetZ = 0;

// Approximate roll and pitch angles, used to determine whether accelerometer
// data can be trusted due to too much tilt of the sensor
float roll = 0;
float pitch = 0;

// Previous loop time in order to calculate delta time
uint32_t lastLoopTime = 0;

// Variable to track errors by function calls
sfeTkError_t err = 0;

// Scaler correction values
volatile float userScalarLinear = 1.0f;
volatile float userScalarAngular = 1.0f;

// Kalmam filters for x and y axes
otosKalmanFilter xKf(1e-8, 1e-6, 1e-4);
otosKalmanFilter yKf(1e-8, 1e-6, 1e-4);
otosKalmanFilter hKf(1e-10, 1e-7, 1e-1);

void setup(void)
{
    // Enable SysTick interrupt, which fires every millisecond and is used to
    // track the system time (see SysTick_Handler() in stm32c0xx_it.c)
    LL_SYSTICK_EnableIT();

    // Enable SPI. For some reason this isn't done by the code generator?
    LL_SPI_Enable(SPI1);

    // Reset I2C registers to ensure they are in a known state
    resetRegisters();

    // Enable the address match, NACK, and STOP interrupts for I2C. The TX and
    // RX interrupts are enabled dynamically when these 3 interrupts are
    // triggered (see I2C1_IRQHandler() in stm32c0xx_it.c)
    LL_I2C_EnableIT_ADDR(I2C1);
    LL_I2C_EnableIT_NACK(I2C1);
    LL_I2C_EnableIT_STOP(I2C1);

    // Calibrate and enable the ADC, which is used to check that the PAA5163 is
    // actually receiving power
    calibrateAndEnableADC();

    // Begin the PAA5163. This should be done before the LSM6DS0, because the
    // ESD diodes on the PAA5163's SPI pins will back-power it, which we don't
    // want. The begin() will power up the PAA5163, after which we can begin
    // the LSM6DS0 safely
    err = paa.begin();
    if(err != kSTkErrOk){
        registerStatus->errorPaa = 1;
        registerStatus->errorPaa1 = 1;
    }

    // Now we can begin the LSM6DS0
    err = lsm.begin();
    if(err != kSTkErrOk)
        registerStatus->errorLsm = 1;

    // Ensure the orientation of the PAA5163 is correct, it defaults to one axis
    // being inverted
    sfe_paa5163_orientation_t orientation;
    orientation.invertX = 0;
    orientation.invertY = 0;
    orientation.swapXY = 0;
    err = paa.setOrientation(orientation);
    if(err != kSTkErrOk){
        registerStatus->errorPaa = 1;
        registerStatus->errorPaa2 = 1;
    }

    // Set PAA5163 resolution to max (20k dpi)
    err = paa.setResolution(kPaa5163MaxResolution, kPaa5163MaxResolution);
    if(err != kSTkErrOk){
        registerStatus->errorPaa = 1;
        registerStatus->errorPaa3 = 1;
    }

    // Set range and data rate for accelerometer and gyro as high as we can, to
    // avoid clipping, and to see short data spikes. 16g and 2000dps is the max
    // of the LSM6DS0, and 416Hz is the max data rate that this application on
    // this MCU can reasonably handle
    err = lsm.setAccelRange(kLsm6dsoAccelRange16g);
    if(err != kSTkErrOk)
        registerStatus->errorLsm = 1;
    err = lsm.setGyroRange(kLsm6dsoGyroRange2000Dps);
    if(err != kSTkErrOk)
        registerStatus->errorLsm = 1;
    err = lsm.setAccelDataRate(kLsm6dsoOdr416Hz);
    if(err != kSTkErrOk)
        registerStatus->errorLsm = 1;
    err = lsm.setGyroDataRate(kLsm6dsoOdr416Hz);
    if(err != kSTkErrOk)
        registerStatus->errorLsm = 1;

    // Enable gyro data ready interrupt, which we will use to synchronize the
    // data from the PAA5163 and LSM6DS0
    err = lsm.setInterrupts(kLsm6dsoInt1Pin, kLsm6dsoInt1SrcDrdyG);
    if(err != kSTkErrOk)
        registerStatus->errorLsm = 1;

    // Testing has shown that the initial data from the LSM6DS0 seems to
    // "oscillate" just after powering on for some reason, despite the sensor
    // being motionless. This typically settles within 100ms, so we'll wait for
    // that to happen before we start calibrating the gyro
    delay(100);

    // Perform a quick calibration of the gyro. This should really only be done
    // when motionless, and we don't know if we are or not. But we'll do it
    // anyway since there's a decent chance that we are motionless if we just
    // reset. Hopefully the user will trigger a proper calibration later!
    calibrateImu(64);
}

void loop()
{
    // Update registers from self shadow registers if needed
    copyRegsFromSelfShadow();

    // Update registers from host shadow registers if needed
    copyRegsFromHostShadow();

    // Update sensor data if needed
    sensorUpdate();
}

void calibrateImu(uint8_t numSamples)
{
    // Variables to store the running sum of raw IMU data, which we'll use to
    // compute the average
    int32_t accSumX = 0;
    int32_t accSumY = 0;
    int32_t gyrSumX = 0;
    int32_t gyrSumY = 0;
    int32_t gyrSumZ = 0;

    // Loop until we get the requested number of samples
    uint8_t counter = numSamples;
    uint32_t timeoutStart = millis();
    while (counter > 0)
    {
        // Check if we've waited for too long (should only be 2.4ms at 416Hz)
        if(millis() - timeoutStart > 10)
        {
            // Timeout occurred, set flag and break out of loop
            registerStatus->errorLsm = 1;
            break;
        }

        // Wait for next data to become available from IMU
        if (!lsmDrdy)
            continue;

        // Reset the data ready flag for the next measurement
        lsmDrdy = false;

        // Reset timeout
        timeoutStart = millis();

        // Grab the IMU data. We use the raw data and convert it later for
        // better efficiency and numerical accuracy
        uint8_t lsmData[12];
        err = lsm.readRawAccelGyroAll(lsmData, 12);
        if(err != kSTkErrOk)
            registerStatus->errorLsm = 1;
        
        // Combine raw bytes into 16-bit signed integers
        int16_t gyrXRaw = (lsmData[1] << 8) | lsmData[0];
        int16_t gyrYRaw = (lsmData[3] << 8) | lsmData[2];
        int16_t gyrZRaw = (lsmData[5] << 8) | lsmData[4];
        int16_t accXRaw = (lsmData[7] << 8) | lsmData[6];
        int16_t accYRaw = (lsmData[9] << 8) | lsmData[8];

        // Add the IMU data to the running sums
        accSumX += accXRaw;
        accSumY += accYRaw;
        gyrSumX += gyrXRaw;
        gyrSumY += gyrYRaw;
        gyrSumZ += gyrZRaw;

        // Decrement the sample counter
        counter--;

        // Update register to inform host of progress
        registerBufferMain[kOtosRegImuCalib] = counter;
    }

    // Reset the last loop time to avoid a large delta time in the main loop
    lastLoopTime = micros();

    // Compute the averages in m/s^2 and radians/second, and store them as the
    // offsets
    accOffsetX = (accSumX * lsm.rawToMps2()) / numSamples;
    accOffsetY = (accSumY * lsm.rawToMps2()) / numSamples;
    gyrOffsetX = (gyrSumX * lsm.rawToRps()) / numSamples;
    gyrOffsetY = (gyrSumY * lsm.rawToRps()) / numSamples;
    gyrOffsetZ = (gyrSumZ * lsm.rawToRps()) / numSamples;
}

void sensorUpdate()
{
    // Check to see if new data is available from the IMU
    if (!lsmDrdy)
    {
        // No new data, nothing to do
        return;
    }

    ////////////////////////////////////////////////////////////////////////////
    // Sensor measurement (time critical section!)
    ////////////////////////////////////////////////////////////////////////////

    // We have new data! Set the output pin to indicate that we're now measuring
    LL_GPIO_SetOutputPin(GPIOA, LL_GPIO_PIN_9);

    // Immediately update the loop timer to get accurate time
    uint32_t loopTime = micros();

    // Reset the data ready flag before we read from the LSM6DSO, because
    // that clears this interrupt, and we need to be ready for the next one
    lsmDrdy = false;

    // Read data from sensors as soon as possible
    uint8_t paaData[12];
    err = paa.readBurstData(paaData, 12);
    if(err != kSTkErrOk)
        registerStatus->errorPaa = 1;
    uint8_t lsmData[12];
    err = lsm.readRawAccelGyroAll(lsmData, 12);
    if(err != kSTkErrOk)
        registerStatus->errorLsm = 1;

    ////////////////////////////////////////////////////////////////////////////
    // Measurement conversion
    ////////////////////////////////////////////////////////////////////////////
    
    // All the time-critical things are done, so we can do some math now. First
    // let's compute the delta time, and save the last loop time
    float dt = (loopTime - lastLoopTime) * 1e-6f;
    float dtInv = 1.0f / dt;
    lastLoopTime = loopTime;
    
    // Combine raw bytes into 16-bit signed integers
    int16_t deltaXRaw = (paaData[3] << 8) | paaData[2];
    int16_t deltaYRaw = (paaData[5] << 8) | paaData[4];
    int16_t deltaRRaw = (lsmData[1] << 8) | lsmData[0];
    int16_t deltaPRaw = (lsmData[3] << 8) | lsmData[2];
    int16_t deltaHRaw = (lsmData[5] << 8) | lsmData[4];
    int16_t accelXRaw = (lsmData[7] << 8) | lsmData[6];
    int16_t accelYRaw = (lsmData[9] << 8) | lsmData[8];

    // Convert the PAA5163 data to meters
    float deltaX = deltaXRaw * paa.rawToMetersX();
    float deltaY = deltaYRaw * paa.rawToMetersY();

    // Convert the gyro data to radians/second, apply the gyro offset
    float vR = (deltaRRaw * lsm.rawToRps() - gyrOffsetX);
    float vP = (deltaPRaw * lsm.rawToRps() - gyrOffsetY);
    float vH = (deltaHRaw * lsm.rawToRps() - gyrOffsetZ);

    // Convert the accelerometer data to m/s^2, and apply the acceleration
    // offset. The IMU is mounted 90 degrees from the PAA5163, so we need to
    // swap the X and Y axes, and negate Y    
    float accelXMps2 = (accelYRaw * lsm.rawToMps2()) - accOffsetY;
    float accelYMps2 = -((accelXRaw * lsm.rawToMps2()) - accOffsetX);

    ////////////////////////////////////////////////////////////////////////////
    // Lookup table calibration
    ////////////////////////////////////////////////////////////////////////////

    // The resolution of the PAA5163 varies with the surface velocity. A lookup
    // table has been implemented that provides a scaling factor to compensate
    // based on the measured velocities, so compute the measured velocities
    float vx = deltaX * dtInv;
    float vy = deltaY * dtInv;

    // Using the measured velocities, determine the scaling factors for each
    // axis using the lookup table. The lookup table requires inches per second
    float xScalar = 1.0f;
    float yScalar = 1.0f;
    if(registerSignalProcess->enLut)
        bilinearInterp(vx * 39.37f, vy * 39.37f, xScalar, yScalar);

    // Scale the velocities by the lookup table scalars, and apply the user
    // defined scalars
    vx *= xScalar * userScalarLinear;
    vy *= yScalar * userScalarLinear;

    ////////////////////////////////////////////////////////////////////////////
    // Tilt detection
    ////////////////////////////////////////////////////////////////////////////

    // Compute roll and pitch angles approximately. Simple integration like this
    // is not technically the right way to do this, but it's not being used for
    // true orientation detection, just to determine if the sensor has been
    // tiled significantly
    roll += vR * dt;
    pitch += vP * dt;

    // As described below, the optical tracking sensor can't always be trusted,
    // such as when the surface properties change suddenly. The solution there
    // is to ignore the optical tracking data if that's detected, and only use
    // the accelerometer data. This works fine under normal conditions, but if 
    // the user tilts the sensor more than ~20 degrees, the accelerometer data
    // causes a false positive detection of tracking issues, which can cause the
    // estimated velocity and position to explode. So if the tilt angles are
    // beyond a threshold (arbitrarily set to 0.2 radians, or 11.5 degrees),
    // we'll set the status flag to indicate that the tilt angle is too high,
    // and the accelerometer data will be ignored later
    if(abs(roll) > 0.2f || abs(pitch) > 0.2f)
        registerStatus->warnTiltAngle = 1;
    else
        registerStatus->warnTiltAngle = 0;

    ////////////////////////////////////////////////////////////////////////////
    // Kalmam filter update (angular)
    ////////////////////////////////////////////////////////////////////////////

    // Apply user-defined scalar for heading
    vH *= userScalarAngular;

    // First run the prediction step
    hKf.predict(dt);

    // Now run the update step with the latest measurement
    hKf.updateVel(vH, 1e-3);

    // Wrap heading to +/- pi
    if (hKf.xData[0] >= kPi)
        hKf.xData[0] -= k2Pi;
    if (hKf.xData[0] < -kPi)
        hKf.xData[0] += k2Pi;

    ////////////////////////////////////////////////////////////////////////////
    // Convert measurements to world frame
    ////////////////////////////////////////////////////////////////////////////

    // Pre-compute sin and cos so we don't have to do it multiple times
    float cosHeading = arm_cos_f32(hKf.xData[0]);
    float sinHeading = arm_sin_f32(hKf.xData[0]);

    // Rotate the measured velocity and acceleration by the heading
    if(registerSignalProcess->enRot)
    {
        float vxRot = vx * cosHeading - vy * sinHeading;
        float vyRot = vx * sinHeading + vy * cosHeading;
        float accelXMps2Rot = accelXMps2 * cosHeading - accelYMps2 * sinHeading;
        float accelYMps2Rot = accelXMps2 * sinHeading + accelYMps2 * cosHeading;

        vx = vxRot;
        vy = vyRot;
        accelXMps2 = accelXMps2Rot;
        accelYMps2 = accelYMps2Rot;
    }

    ////////////////////////////////////////////////////////////////////////////
    // Kalman filter update (linear)
    ////////////////////////////////////////////////////////////////////////////

    // First run the prediction step
    xKf.predict(dt);
    yKf.predict(dt);

    // Now run the update steps with the latest measurements. If the tilt angle
    // is sufficiently low, we'll use the data from both the accelerometer and
    // optical sensor, otherwise we'll only use the optical sensor data
    if(registerSignalProcess->enAcc && registerStatus->warnTiltAngle == 0)
    {
        // Acceleration update
        xKf.updateAcc(accelXMps2, 9e-4 * registerSignalProcess->enVar);
        yKf.updateAcc(accelYMps2, 9e-4 * registerSignalProcess->enVar);

        // Sometimes the velocity measured by the PAA5163 drops very low, which
        // is usually caused by tracking issues (eg. debris or a sudden change
        // in surface properties). We can detect this if the measured velocity
        // is significantly lower than the estimated velocity, in which case we
        // can ignore the measurement
        if(!((abs(vx) + abs(vy)) < .25 && (abs(xKf.xData[1]) + abs(yKf.xData[1])) > .5))
        {
            // Velocity update
            xKf.updateVel(vx, 6e-3f * registerSignalProcess->enVar);
            yKf.updateVel(vy, 6e-3f * registerSignalProcess->enVar);

            // Reset the warning flag
            registerStatus->warnOpticalTracking = 0;
        }
        else
        {
            // Set the warning flag
            registerStatus->warnOpticalTracking = 1;
        }
    }
    else
    {
        // Not using the accelerometer data, just do the velocity update
        xKf.updateVel(vx, 6e-3 * registerSignalProcess->enVar);
        yKf.updateVel(vy, 6e-3 * registerSignalProcess->enVar);
    }

    ////////////////////////////////////////////////////////////////////////////
    // Compute host position, velocity, and acceleration
    ////////////////////////////////////////////////////////////////////////////

    // Here we compute the host position, velocity, and acceleration in the
    // world frame. The equations below are very similar to what's used in
    // transformPose(), but we're doing them explicitly here to avoid computing
    // sine and cosine more than needed. Additionally, the velocity and
    // acceleration have to be computed slightly differently

    // Host position
    posHost.x = xKf.xData[0] + (posOffsetInv.x * cosHeading - posOffsetInv.y * sinHeading);
    posHost.y = yKf.xData[0] + (posOffsetInv.x * sinHeading + posOffsetInv.y * cosHeading);
    posHost.h = hKf.xData[0] + posOffsetInv.h;

    // Host velocity
    pose2d velHost;
    velHost.x = xKf.xData[1] + (-posOffsetInv.x * sinHeading - posOffsetInv.y * cosHeading) * hKf.xData[1];
    velHost.y = yKf.xData[1] + (posOffsetInv.x * cosHeading - posOffsetInv.y * sinHeading) * hKf.xData[1];
    velHost.h = hKf.xData[1];

    // Host acceleration
    pose2d accHost;
    float centripetalAcceleration = sqrtf(posOffsetInv.x * posOffsetInv.x + posOffsetInv.y * posOffsetInv.y) * hKf.xData[1] * hKf.xData[1];
    accHost.x = xKf.xData[2] + (-posOffsetInv.x * sinHeading - posOffsetInv.y * cosHeading) * hKf.xData[2]
                - (centripetalAcceleration * cosHeading - centripetalAcceleration * sinHeading);
    accHost.y = yKf.xData[2] + (posOffsetInv.x * cosHeading - posOffsetInv.y * sinHeading) * hKf.xData[2]
                - (centripetalAcceleration * sinHeading + centripetalAcceleration * cosHeading);
    accHost.h = hKf.xData[2];

    ////////////////////////////////////////////////////////////////////////////
    // Update shadow registers
    ////////////////////////////////////////////////////////////////////////////

    // Convert host position, velocity, and acceleration to integers in
    // preparation for storing in the shadow registers
    int16_t pxInt = posHost.x * kMeterToInt16;
    int16_t pyInt = posHost.y * kMeterToInt16;
    int16_t phInt = posHost.h * kRadToInt16;
    int16_t vxInt = velHost.x * kMpsToInt16;
    int16_t vyInt = velHost.y * kMpsToInt16;
    int16_t vhInt = velHost.h * kRpsToInt16;
    int16_t axInt = accHost.x * kMpssToInt16;
    int16_t ayInt = accHost.y * kMpssToInt16;
    int16_t ahInt = accHost.h * kRpssToInt16;

    // Compute standard deviation of the Kalman filter covariance matrices
    int16_t pxStdInt = sqrtf(xKf.pData[kOtosKfIdx00]) * kMeterToInt16;
    int16_t pyStdInt = sqrtf(yKf.pData[kOtosKfIdx00]) * kMeterToInt16;
    int16_t phStdInt = sqrtf(hKf.pData[kOtosKfIdx00]) * kRadToInt16;
    int16_t vxStdInt = sqrtf(xKf.pData[kOtosKfIdx11]) * kMpsToInt16;
    int16_t vyStdInt = sqrtf(yKf.pData[kOtosKfIdx11]) * kMpsToInt16;
    int16_t vhStdInt = sqrtf(hKf.pData[kOtosKfIdx11]) * kRpsToInt16;
    int16_t axStdInt = sqrtf(xKf.pData[kOtosKfIdx22]) * kMpssToInt16;
    int16_t ayStdInt = sqrtf(yKf.pData[kOtosKfIdx22]) * kMpssToInt16;
    int16_t ahStdInt = sqrtf(hKf.pData[kOtosKfIdx22]) * kRpssToInt16;

    // Now store the raw register data into the shadow buffer
    registerShadowSelf[kOtosRegPosXL] = pxInt & 0xFF;
    registerShadowSelf[kOtosRegPosXH] = (pxInt >> 8) & 0xFF;
    registerShadowSelf[kOtosRegPosYL] = pyInt & 0xFF;
    registerShadowSelf[kOtosRegPosYH] = (pyInt >> 8) & 0xFF;
    registerShadowSelf[kOtosRegPosHL] = phInt & 0xFF;
    registerShadowSelf[kOtosRegPosHH] = (phInt >> 8) & 0xFF;
    registerShadowSelf[kOtosRegVelXL] = vxInt & 0xFF;
    registerShadowSelf[kOtosRegVelXH] = (vxInt >> 8) & 0xFF;
    registerShadowSelf[kOtosRegVelYL] = vyInt & 0xFF;
    registerShadowSelf[kOtosRegVelYH] = (vyInt >> 8) & 0xFF;
    registerShadowSelf[kOtosRegVelHL] = vhInt & 0xFF;
    registerShadowSelf[kOtosRegVelHH] = (vhInt >> 8) & 0xFF;
    registerShadowSelf[kOtosRegAccXL] = axInt & 0xFF;
    registerShadowSelf[kOtosRegAccXH] = (axInt >> 8) & 0xFF;
    registerShadowSelf[kOtosRegAccYL] = ayInt & 0xFF;
    registerShadowSelf[kOtosRegAccYH] = (ayInt >> 8) & 0xFF;
    registerShadowSelf[kOtosRegAccHL] = ahInt & 0xFF;
    registerShadowSelf[kOtosRegAccHH] = (ahInt >> 8) & 0xFF;
    registerShadowSelf[kOtosRegPosStdXL] = pxStdInt & 0xFF;
    registerShadowSelf[kOtosRegPosStdXH] = (pxStdInt >> 8) & 0xFF;
    registerShadowSelf[kOtosRegPosStdYL] = pyStdInt & 0xFF;
    registerShadowSelf[kOtosRegPosStdYH] = (pyStdInt >> 8) & 0xFF;
    registerShadowSelf[kOtosRegPosStdHL] = phStdInt & 0xFF;
    registerShadowSelf[kOtosRegPosStdHH] = (phStdInt >> 8) & 0xFF;
    registerShadowSelf[kOtosRegVelStdXL] = vxStdInt & 0xFF;
    registerShadowSelf[kOtosRegVelStdXH] = (vxStdInt >> 8) & 0xFF;
    registerShadowSelf[kOtosRegVelStdYL] = vyStdInt & 0xFF;
    registerShadowSelf[kOtosRegVelStdYH] = (vyStdInt >> 8) & 0xFF;
    registerShadowSelf[kOtosRegVelStdHL] = vhStdInt & 0xFF;
    registerShadowSelf[kOtosRegVelStdHH] = (vhStdInt >> 8) & 0xFF;
    registerShadowSelf[kOtosRegAccStdXL] = axStdInt & 0xFF;
    registerShadowSelf[kOtosRegAccStdXH] = (axStdInt >> 8) & 0xFF;
    registerShadowSelf[kOtosRegAccStdYL] = ayStdInt & 0xFF;
    registerShadowSelf[kOtosRegAccStdYH] = (ayStdInt >> 8) & 0xFF;
    registerShadowSelf[kOtosRegAccStdHL] = ahStdInt & 0xFF;
    registerShadowSelf[kOtosRegAccStdHH] = (ahStdInt >> 8) & 0xFF;

    // Also store the raw LSM6DSO and PAA5163 data into the shadow buffer
    memcpy(registerShadowSelf + kOtosRegLsmGyrXL, lsmData, 12);
    memcpy(registerShadowSelf + kOtosRegPaaBurst00, paaData, 12);
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

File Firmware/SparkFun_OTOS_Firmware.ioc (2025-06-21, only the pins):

Mcu.UserName=STM32C011F6Ux
PA0.GPIO_Label=MEAS_1V8
PA0.Signal=ADC1_IN0
PA1.Signal=SPI1_SCK
PA13.Signal=DEBUG_SWDIO
PA14-BOOT0.Signal=DEBUG_SWCLK
PA2.Signal=SPI1_MOSI
PA3.GPIO_Label=LSM_INT
PA3.Signal=GPXTI3
PA4.GPIO_Label=PAA_RST
PA4.Signal=GPIO_Output
PA5.GPIO_Label=PAA_CS
PA5.Signal=GPIO_Output
PA6.Signal=SPI1_MISO
PA7.GPIO_Label=PAA_MOTION
PA7.Signal=GPIO_Input
PA8.GPIO_Label=LSM_CS
PA8.Signal=GPIO_Output
PB6.Signal=I2C1_SCL
PB7.Signal=I2C1_SDA

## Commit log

2025-11-20 tinty tiny
    [Optical_Tracking_Odometry_Sensor.kicad_pcb]
2026-09-27 Updated PCB and Readme
    [Optical_Tracking_Odometry_Sensor.kicad_pcb, Optical_Tracking_Odometry_Sensor.kicad_sch, Optical_Tracking_Odometry_Sensor_Panel.kicad_pcb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]
2026-09-27 Updated cad with 3d model
    [Optical_Tracetry_Sensor.step, Optical_Tracking_Odometry_Sensor.kicad_pcb, Optical_Tracking_Odometry_Sensor.kicad_sch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]
